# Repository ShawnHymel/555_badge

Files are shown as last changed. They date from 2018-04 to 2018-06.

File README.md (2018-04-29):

555 Badge
=========
Badge project based on a 555 timer circuit. Users can follow along with the Digi-Key video series to design and fabricate their own badge PCB. This repository stores all the completed PCB design files. Click [here to watch the video series](https://www.youtube.com/watch?v=vaCVh2SAZY4&index=1&list=PLEBQazB0HUyR24ckSZ5u05TZHV9khgA1O&t=0s).

Introduction to KiCad - Design your own PCB (https://www.youtube.com/watch?v=vaCVh2SAZY4&index=1&list=PLEBQazB0HUyR24ckSZ5u05TZHV9khgA1O&t=0s)

Repository Contents
-------------------
* **555_Badge_BOM** - Bill of materials necessary for building the badge
* **/Hardware** - KiCad design files and gerbers to create 1 badge
* **/Images** - Various logos and other images used in the PCB design
* **/Production** - PCBs panelized for a production run (9 badges per panel)

License Information
-------------------
The hardware is released under [Creative Commons Attribution 4.0 International (CC BY 4.0)](https://creativecommons.org/licenses/by/4.0/).

Distributed as-is; no warranty is given.

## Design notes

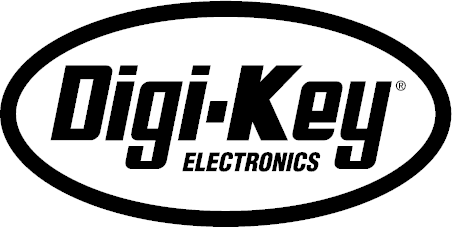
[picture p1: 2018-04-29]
Images/DK_Electronics_Vector_Black_no-outline.png

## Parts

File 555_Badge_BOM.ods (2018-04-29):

Reference | Quantity | Value | Footprint | MPN | Digi-Key PN | Price | Total Price | Part Page
BAT1 | 1 | BS-7 | digikey-footprints:Battery_Holder_Coin_2032_BS-7 | BS-7 | BS-7-ND | $0.79 | $0.79 | https://www.digikey.com/product-detail/en/mpd-memory-protection-devices/BS-7/BS-7-ND/389447
Battery | 1 |  |  | CR2032 | P189-ND | $0.29 | $0.29 | https://www.digikey.com/product-detail/en/panasonic-bsg/CR2032/P189-ND/31939
C1 | 1 | 10uF | Capacitors_THT:CP_Radial_D5.0mm_P2.00mm | ECA-1HM100 | P5178-ND | $0.18 | $0.18 | https://www.digikey.com/product-detail/en/panasonic-electronic-components/ECA-1HM100/P5178-ND/245037
C2 | 1 | 100uF | Capacitors_THT:CP_Radial_D6.3mm_P2.50mm | 35ZLH100MEFC6.3X11 | 1189-1300-ND | $0.31 | $0.31 | https://www.digikey.com/product-detail/en/rubycon/35ZLH100MEFC6.3X11/1189-1300-ND/3134256
D1 D2 | 2 | RED | LEDs:LED_D3.0mm | MT7403A-UR-A | 1125-1181-ND | $0.42 | $0.84 | https://www.digikey.com/product-detail/en/marktech-optoelectronics/MT7403A-UR-A/1125-1181-ND/4214630
Q1 | 1 | 2N3904 | digikey-footprints:TO-92-3 | 2N3904BU | 2N3904FS-ND | $0.21 | $0.21 | https://www.digikey.com/product-detail/en/on-semiconductor/2N3904BU/2N3904FS-ND/1413
R1 R3 | 2 | 22k | Resistors_THT:R_Axial_DIN0207_L6.3mm_D2.5mm_P7.62mm_Horizontal | CF14JT22K0 | CF14JT22K0CT-ND | $0.10 | $0.20 | https://www.digikey.com/product-detail/en/stackpole-electronics-inc/CF14JT22K0/CF14JT22K0CT-ND/1830383
R2 | 1 | 330k | Resistors_THT:R_Axial_DIN0207_L6.3mm_D2.5mm_P7.62mm_Horizontal | CF14JT330K | CF14JT330KCT-ND | $0.10 | $0.10 | https://www.digikey.com/product-detail/en/stackpole-electronics-inc/CF14JT330K/CF14JT330KCT-ND/1830411
R4 | 1 | 100k | Resistors_THT:R_Axial_DIN0207_L6.3mm_D2.5mm_P7.62mm_Horizontal | CF14JT100K | CF14JT100KCT-ND | $0.10 | $0.10 | https://www.digikey.com/product-detail/en/stackpole-electronics-inc/CF14JT100K/CF14JT100KCT-ND/1830399
R5 | 1 | 10k | Resistors_THT:R_Axial_DIN0207_L6.3mm_D2.5mm_P7.62mm_Horizontal | CF14JT10K0 | CF14JT10K0CT-ND | $0.10 | $0.10 | https://www.digikey.com/product-detail/en/stackpole-electronics-inc/CF14JT10K0/CF14JT10K0CT-ND/1830374
R6 R7 | 2 | 100 | Resistors_THT:R_Axial_DIN0207_L6.3mm_D2.5mm_P7.62mm_Horizontal | CF14JT100R | CF14JT100RCT-ND | $0.10 | $0.20 | https://www.digikey.com/product-detail/en/stackpole-electronics-inc/CF14JT100R/CF14JT100RCT-ND/1830327
S1 | 1 | EG1218 | digikey-footprints:Switch_Slide_11.6x4mm_EG1218 | EG1218 | EG1903-ND | $0.58 | $0.58 | https://www.digikey.com/product-detail/en/e-switch/EG1218/EG1903-ND/101726
U1 | 1 | 7555 | 555_Badge:ICM7555-PDIP | ICM7555IPAZ | ICM7555IPAZ-ND | $0.83 | $0.83 | https://www.digikey.com/product-detail/en/intersil/ICM7555IPAZ/ICM7555IPAZ-ND/821488

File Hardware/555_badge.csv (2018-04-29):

Id | Designator | Package | Quantity | Designation | Supplier and ref
1 | D1,D2 | LED_D3.0mm | 2 | RED
2 | U1 | ICM7555-PDIP | 1 | 7555
3 | C1 | CP_Radial_D5.0mm_P2.00mm | 1 | 10uF
4 | C2 | CP_Radial_D6.3mm_P2.50mm | 1 | 100uF
5 | Q1 | TO-92-3 | 1 | 2N3904
6 | R1,R3 | R_Axial_DIN0207_L6.3mm_D2.5mm_P7.62mm_Horizontal | 2 | 22k
7 | R2 | R_Axial_DIN0207_L6.3mm_D2.5mm_P7.62mm_Horizontal | 1 | 330k
8 | R4 | R_Axial_DIN0207_L6.3mm_D2.5mm_P7.62mm_Horizontal | 1 | 100k
9 | R5 | R_Axial_DIN0207_L6.3mm_D2.5mm_P7.62mm_Horizontal | 1 | 10k
10 | R6,R7 | R_Axial_DIN0207_L6.3mm_D2.5mm_P7.62mm_Horizontal | 2 | 100
11 | BAT1 | BS-7 | 1 | BS-7
12 | S1 | EG1218 | 1 | EG1218

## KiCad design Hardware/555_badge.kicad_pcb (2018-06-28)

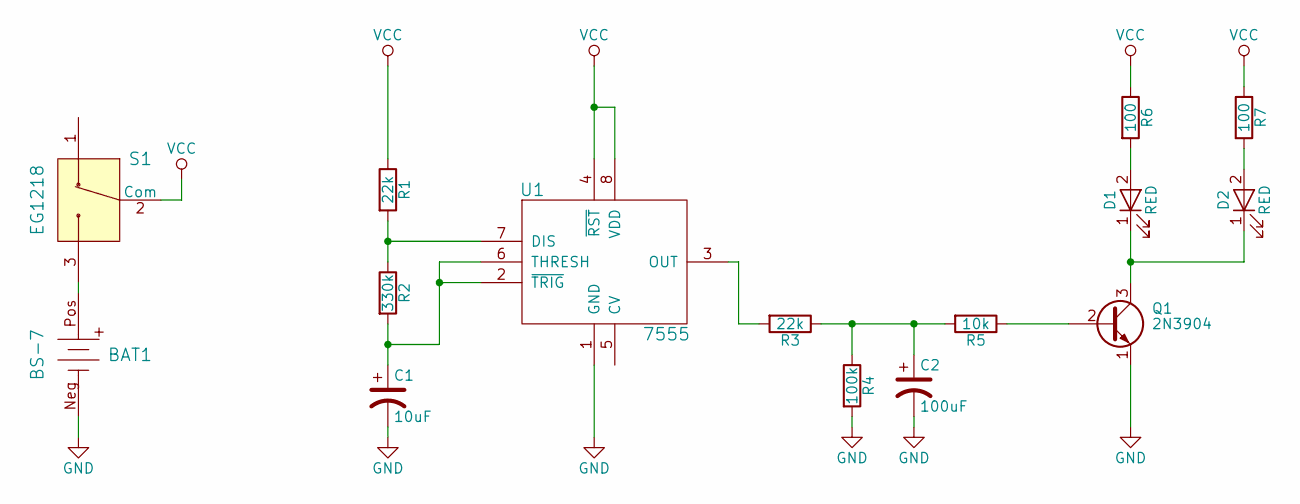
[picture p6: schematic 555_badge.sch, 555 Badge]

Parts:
BAT1: BS-7; MPN BS-7; Digi-Key_PN BS-7-ND
C1: 10uF; CP_Radial_D5.0mm_P2.00mm
C2: 100uF; CP_Radial_D6.3mm_P2.50mm
D1, D2: RED; LED_D3.0mm
Q1: 2N3904; TO-92-3
R1, R3: 22k; R_Axial_DIN0207_L6.3mm_D2.5mm_P7.62mm_Horizontal
R2: 330k; R_Axial_DIN0207_L6.3mm_D2.5mm_P7.62mm_Horizontal
R4: 100k; R_Axial_DIN0207_L6.3mm_D2.5mm_P7.62mm_Horizontal
R5: 10k; R_Axial_DIN0207_L6.3mm_D2.5mm_P7.62mm_Horizontal
R6, R7: 100; R_Axial_DIN0207_L6.3mm_D2.5mm_P7.62mm_Horizontal
S1: EG1218; MPN EG1218; Digi-Key_PN EG1903-ND
U1: 7555; ICM7555-PDIP

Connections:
GND: BAT1.Neg, C1.2, C2.2, Q1.1 (E), R4.2, U1.1 (GND)
unnamed: BAT1.Pos, S1.3
unnamed: C1.1, R2.2, U1.2 (~TRIG), U1.6 (THRESH)
unnamed: C2.1, R3.1, R4.1, R5.2
unnamed: D1.1 (K), D2.1 (K), Q1.3 (C)
unnamed: D1.2 (A), R6.2
unnamed: D2.2 (A), R7.2
unnamed: Q1.2 (B), R5.1
unnamed: R1.2, R2.1, U1.7 (DIS)
unnamed: R3.2, U1.3 (OUT)
VCC: R1.1, R6.1, R7.1, S1.2 (Com), U1.4 (~RST), U1.8 (VDD)

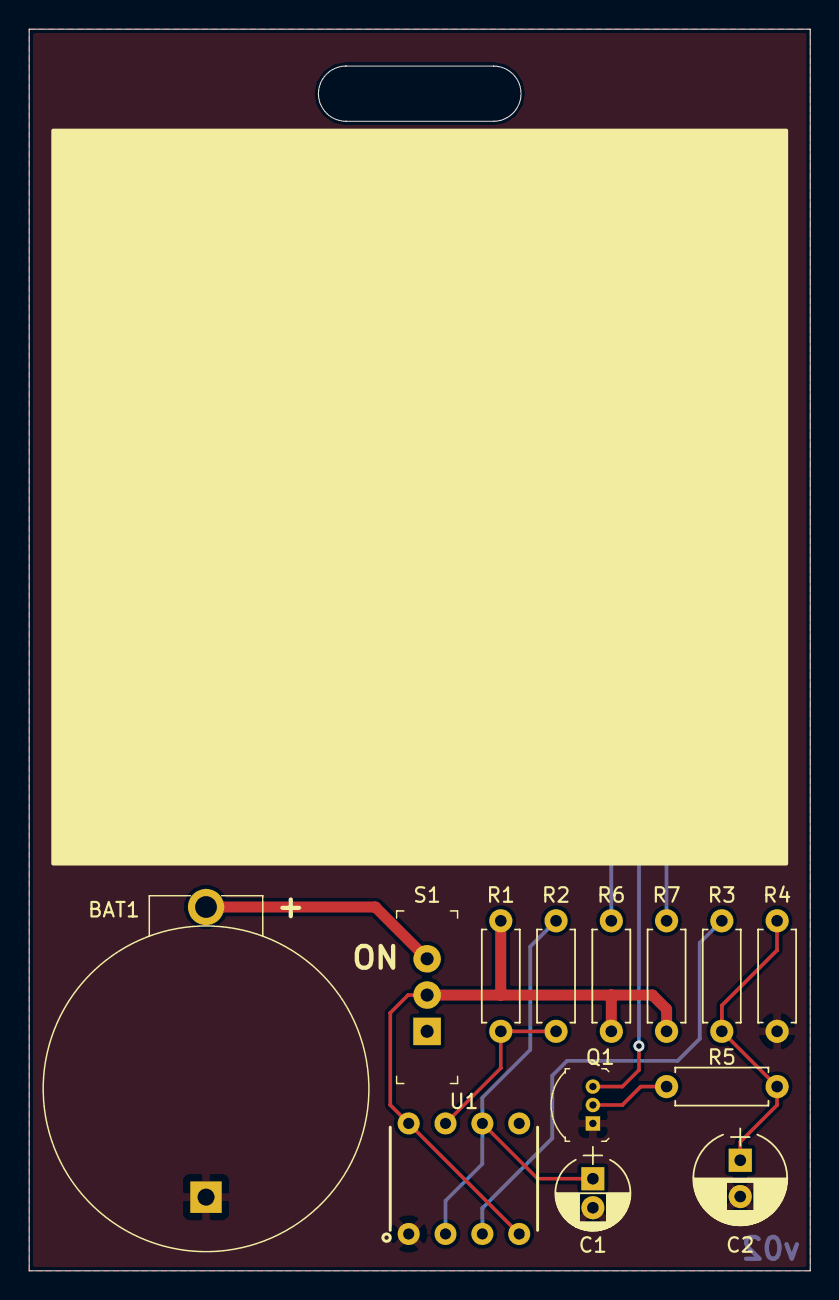
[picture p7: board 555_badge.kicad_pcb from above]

Board: 2 copper layers, 53.8 x 85.6 mm, 15 parts (0 on the bottom side), 11 nets.

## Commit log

2017-12-27 v00 complete and sent to fab
    [555_badge-B.Cu.gbl, 555_badge-B.Mask.gbs, 555_badge-B.SilkS.gbo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]
2018-01-12 v00a. Flipped LEDs, disconnected CV on 7555, widened slot.
    [555_badge-B.Cu.gbl, 555_badge-B.Mask.gbs, 555_badge-B.SilkS.gbo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]
2018-01-14 Changed R2 to 330k
    [555_badge.kicad_pcb, 555_badge.sch]
2018-04-29 Added some silk. Updated to v02. Panelized design. Created README.
    [555_Badge_BOM.ods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]
2018-04-30 Added D1 and D2 refdes to back
    [555_badge-B.Cu.gbl, 555_badge-B.Mask.gbs, 555_badge-B.SilkS.gbo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]
2018-06-28 Flipped transistor silk
    [555_badge.kicad_pcb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]

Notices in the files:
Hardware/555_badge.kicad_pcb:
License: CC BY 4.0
